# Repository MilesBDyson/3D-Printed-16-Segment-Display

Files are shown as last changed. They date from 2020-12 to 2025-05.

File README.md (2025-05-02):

  This 16 Segment Display has 16 2x3x4 mm square LED's and no Decimal Point.
  
  I did allow tolerances for fitting, however depending on your Printer you may need to adjust
  the temp accordingly if parts fit two tight print them a bit cooler. it will make a huge difference.
  
  Base can be printed out with any color you like
  Segments were printed with translucent Red with Red LED's
  
  The Display is NOT PCB compliant.
  can be driven by 2 X 74HC595 shift registers per Digit. 
  The PCB can be Dasie Chained to create large display arrays
  Operating Voltage for the display is 5v.

  Thingiverse
  
  Parts:
  
  2 x 74HC595
  
  2 x 2 pin Multilayer Ceramic Capacitors 'A5E104M'
  
  16 x 2x3x4 mm squar LED's
  
  16 x 470ohm resistors
  
  32 x Male Headder Pins
  
  Wrapping Wire was used for the connections 'AWG30'

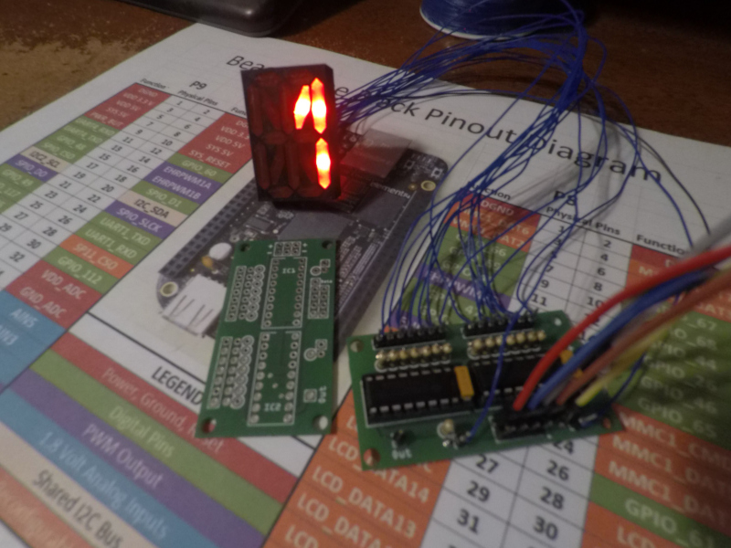
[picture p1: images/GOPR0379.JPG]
  
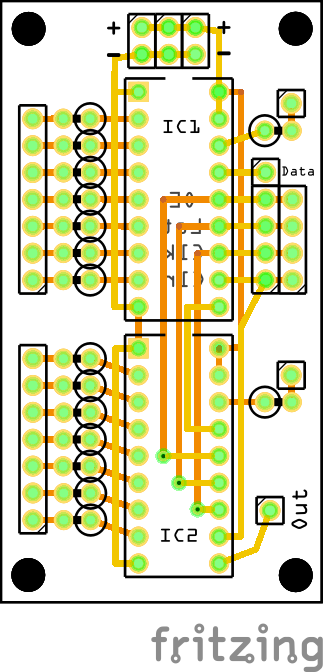
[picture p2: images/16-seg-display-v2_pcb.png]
  
  

  Hits (https://hits.sh/github.com/MilesBDyson/3D-Printed-16-Segment-Display/)

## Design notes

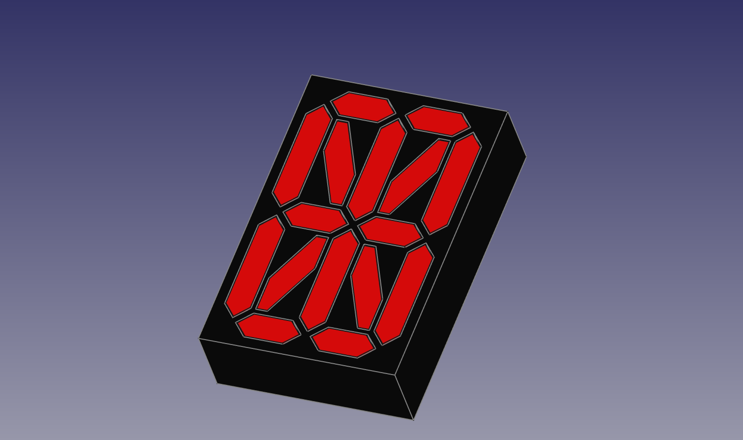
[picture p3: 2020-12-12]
images/Med-16-seg.png

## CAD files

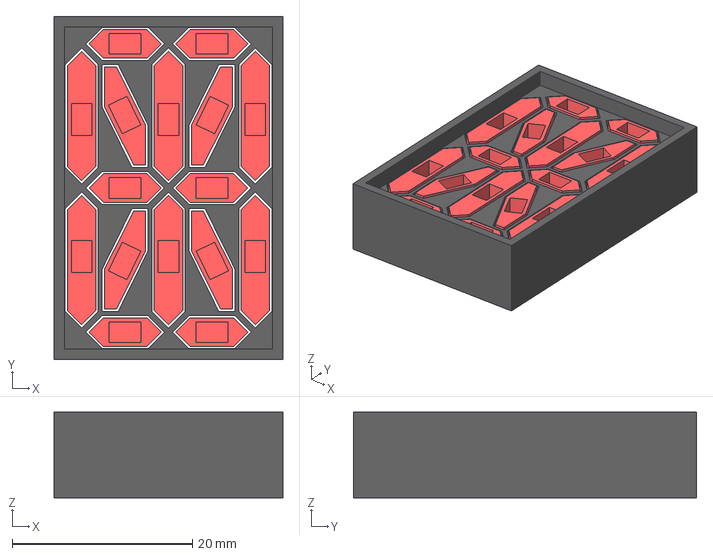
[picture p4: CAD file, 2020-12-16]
CAD/16-seg.FCStd
25.4 x 38.1 x 9.53 mm
Frame
Digit

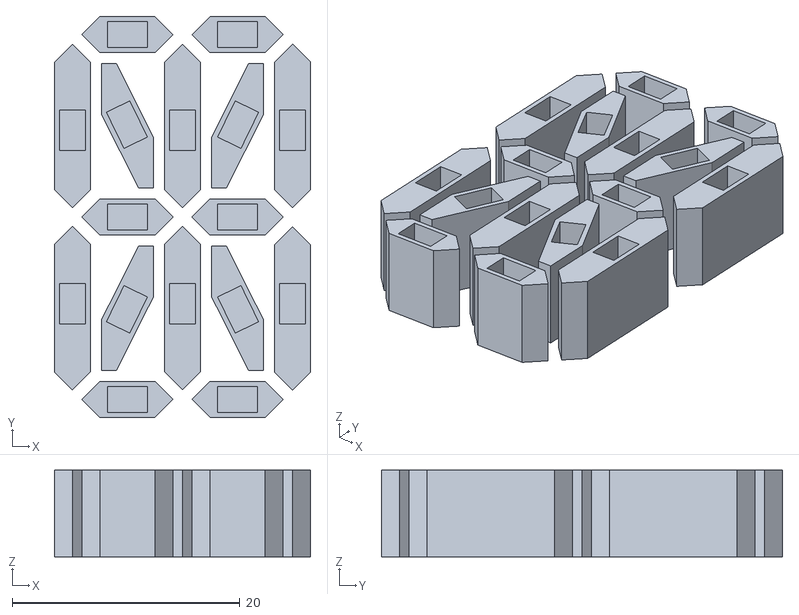
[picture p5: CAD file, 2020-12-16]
STL/med-16-seg-digit.stl
22.5 x 35.2 x 7.62

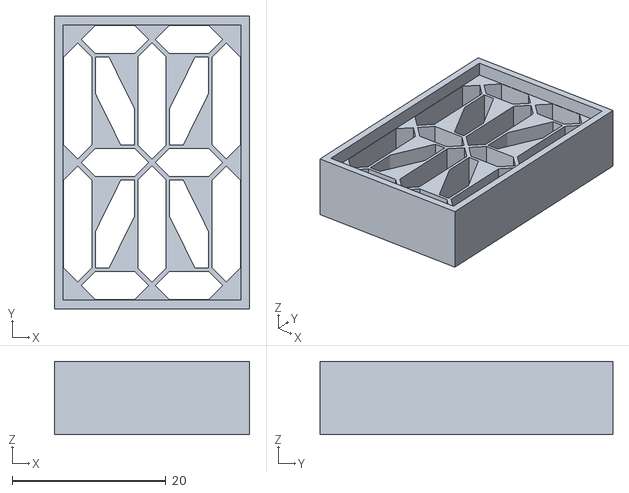
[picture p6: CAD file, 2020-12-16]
STL/med-16-seg-frame.stl
25.4 x 38.1 x 9.52

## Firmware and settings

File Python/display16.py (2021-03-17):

#!/usr/bin/python

import Adafruit_BBIO.GPIO as GPIO
from time import sleep
from random import randint

# this example uses a single shift register with normal 2-pin LED's

'''
SER   = Data
RCLK  = Latch
SRCLK = Clock
SRCLR = Clear (keep high)
OE    = Blank (keep low)

       74HC595
       -------
 QB --|1    16|-- VCC
 QC --|2    15|-- QA
 QD --|3    14|-- SER
 QE --|4    13|-- OE
 QF --|5    12|-- RCLK
 QG --|6    11|-- SRCLK
 QH --|7    10|-- SRCLR
GND --|8     9|-- QH'           <--- DATA OUT to SER on next IC to daisy chain them
       -------
'''

data_pin  = "P8_8"
latch_pin = "P8_10"
clock_pin = "P8_12"
clear_pin = "P8_14"
blank_pin = "P8_16"

# Setup Pins
GPIO.setup(data_pin, GPIO.OUT)
GPIO.setup(latch_pin, GPIO.OUT)
GPIO.setup(clock_pin, GPIO.OUT)
GPIO.setup(clear_pin, GPIO.OUT)
GPIO.setup(blank_pin, GPIO.OUT)

# Set Pin State
GPIO.output(data_pin, GPIO.LOW)
GPIO.output(latch_pin, GPIO.LOW)
GPIO.output(clock_pin, GPIO.LOW)
#GPIO.output(clear_pin, GPIO.LOW)
GPIO.output(clear_pin, GPIO.HIGH)
GPIO.output(blank_pin, GPIO.LOW)


def delay(millis):
    millis_to_seconds = float(millis)/1000
    return sleep(millis_to_seconds)
    
char = {
     '0': '1111111100100010',
     '1': '0000010000001100',
     '2': '1000100001110111',
     '3': '0000100000111111',
     '4': '0011000111000000',
     '5': '1001000010110011',
     '6': '1000100011111011',
     '7': '0000000000001111',
     '8': '1000100011111111',
     '9': '1000100010111111',
     'A': '1000100011001111',
     'B': '0010101000111111',
     'C': '0000000011110011',
     'D': '0010001000111111',
     'E': '1000000011110011',
     'F': '1000000011000011',
     'G': '0000100011111011',
     'H': '1000100011001100',
     'I': '0010001000110011',
     'J': '0000000001111100',
     'K': '1001010011000000',
     'L': '0000000011110000',
     'M': '0000010111001100',
     'N': '0001000111001100',
     'O': '0000000011111111',
     'P': '1000100011000111',
     'Q': '0001000011111111',
     'R': '1001100011000111',
     'S': '1000100010111011',
     'T': '0010001000000011',
     'U': '0000000011111100',
     'V': '0100010011000000',
     'W': '0101000011001100',
     'X': '0101010100000000',
     'Y': '1000100010111100',
     'Z': '0100010000110011',
     'a': '1010000001110000',
     'b': '1010000011100000',
     'c': '1000000001100000',
     'd': '0010100000011100',
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
}



output = char['1']
print (output)
GPIO.output(clear_pin, GPIO.LOW)
GPIO.output(clear_pin, GPIO.HIGH)
GPIO.output(latch_pin, GPIO.HIGH)
GPIO.output(latch_pin, GPIO.LOW)
for c in output:
   print(c)
   if c == '1':
      GPIO.output(data_pin, GPIO.HIGH)
      GPIO.output(clock_pin, GPIO.HIGH)
      GPIO.output(clock_pin, GPIO.LOW)
      GPIO.output(data_pin, GPIO.LOW)
   if c == '0':
      GPIO.output(clock_pin, GPIO.HIGH)
      GPIO.output(clock_pin, GPIO.LOW)

GPIO.output(latch_pin, GPIO.HIGH)
GPIO.output(latch_pin, GPIO.LOW)

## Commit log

2020-12-12 fix clearance
    [16-seg.FCStd, med-16-seg-digit.stl, med-16-seg-frame.stl]
2020-12-12 added new image
    [16-seg.FCStd]
2020-12-16 miner changes
    [16-seg.FCStd, 3x-16-seg.FCStd, 3x-med-16-seg-disp.stl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]
2021-03-17 added program
    [16-seg-display-v2.fzz]
2021-03-17 Clean up
    [16-seg.FCStd, 3x-16-seg.FCStd, 3x-med-16-seg-disp.stl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]
